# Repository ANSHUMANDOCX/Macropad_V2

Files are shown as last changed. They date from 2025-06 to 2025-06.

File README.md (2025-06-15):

## MACROPAD

This is a 20-key macropad with 2 rotary encoders, 2 analog slide potentiometers, and a 0.91" OLED display.

---

## List of Components

- Pro Micro RP2040  
- SSD1306 0.91" OLED  
- 20 MX-style keys  
- 2 Encoders  
- 2 PTA0643 Slide Potentiometers  
- WS2812B 2020 RGB LEDs  

---

## Plan

I wanted to make a macropad with enough keys for my purpose. I started out by getting a microcontroller with enough pins and one that is able to run CircuitPython, since I wanted to use KMK as the firmware. This can be programmed for MIDI control as well.  
It also has RGB LEDs for underglow.

The OLED screen will be attached via the QWIIC connector onboard.

---

## PCB and Case





## BOM 
### 📦 Component Cost Table

| Item | Supplier | Price (USD) |
|---|---|---|
| Screw & bolt | LCSC | 0.34 |
| Rotary Encoder (DIP-5) | LCSC | 3.01 |
| PTA6043 Potentiometer (10kΩ) | LCSC | 3.37 |
| 1N4148 Diode | LCSC | 0.84 |
|WS2812B 2020 RGB led | LCSC | 1.67 |
|SSD1306 0.91" OLED Display | LCSC | 2.01 |
| SL2.1A | LCSC |1.22 |
| USB A Female | LCSC |0.74 |
| Shipping (LCSC) | LCSC |  3.73 |
| RP2040 Pro Micro + Qwiic | Electronics Comp | 19.43 |
| Keycaps and Keys | Stackskb | 15.88 |
| PCB | JLCPCB | 9.00 |
| Shipping | JLCPCB | 14.00 |
| **Total** | | **$75.24** |

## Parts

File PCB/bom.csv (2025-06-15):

Designator | Footprint | Quantity | Value | LCSC Part #
C1, C2 | 0805 | 2 | 10uF
D1, D10, D11, D12, D13, D14, D15, D16, D17, D18, D19, D2, D20, D3, D4, D5, D6, D7, D8, D9 | D_DO-35_SOD27_P7.62mm_Horizontal | 20 | 1N4148
D21, D22, D23, D24, D25, D26, D27, D28, D29, D30, D31, D32, D33, D34, D35 | LED_WS2812B-2020_PLCC4_2.0x2.0mm | 15 | WS2812B-2020
DM1, DM2, DM3, DM4, DP1, DP2, DP3, DP4, TP11, TP12 | TestPoint_Pad_D1.5mm | 10 | TestPoint
J1 | USB_C_Receptacle_GCT_USB4105-xx-A_16P_TopMnt_Horizontal | 1 | USB_C_Receptacle_USB2.0_16P
R1, R2 | 0603 | 2 | 5.1k
RV1, RV2 | Potentiometer_Bourns_PTA6043_Single_Slide | 2 | R_Potentiometer
SW1, SW10, SW11, SW12, SW13, SW14, SW15, SW16, SW17, SW18, SW19, SW2, SW20, SW3, SW4, SW5, SW6, SW7, SW8, SW9 | CHERRY | 20 | SW_Push
SW21, SW22 | RotaryEncoder_Alps_EC11E-Switch_Vertical_H20mm_CircularMountingHoles | 2 | RotaryEncoder_Switch
TP1 | TestPoint_Pad_D1.0mm | 1 | TestPoint
U1 | MODULE_DEV-18288 | 1 | DEV-18288
U2 | SOIC-16_4.55x10.3mm_P1.27mm | 1 | SL2.1A

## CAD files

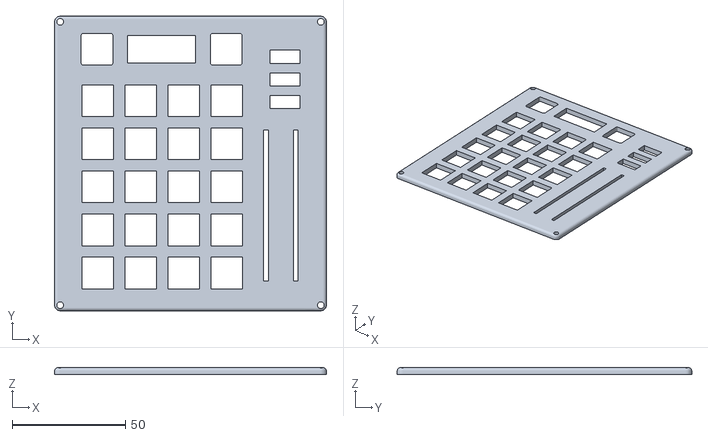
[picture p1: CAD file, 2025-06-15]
CAD/Front Plate v20.stl
120.0 x 130.0 x 3.00

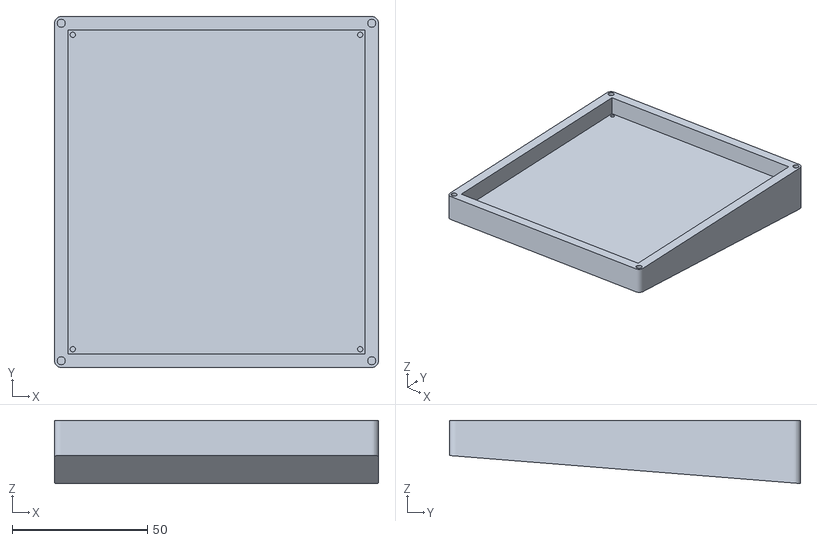
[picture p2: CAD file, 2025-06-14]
CAD/BASE PLATE v6.stl
120.0 x 130.0 x 23.4

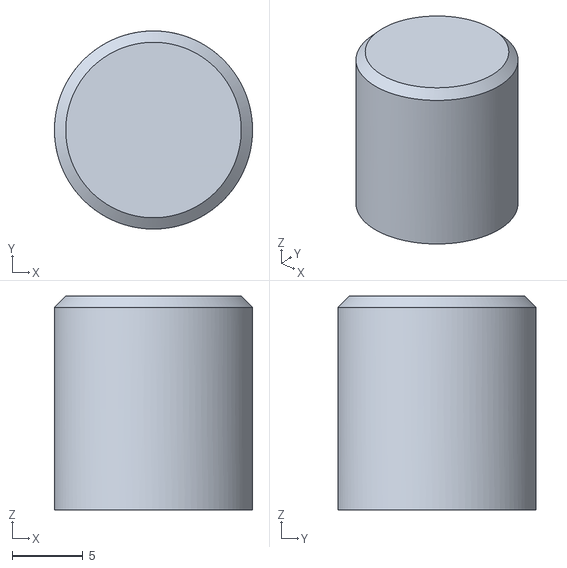
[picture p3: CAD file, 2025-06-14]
CAD/DIAL v1.stl
14.0 x 14.0 x 15.1

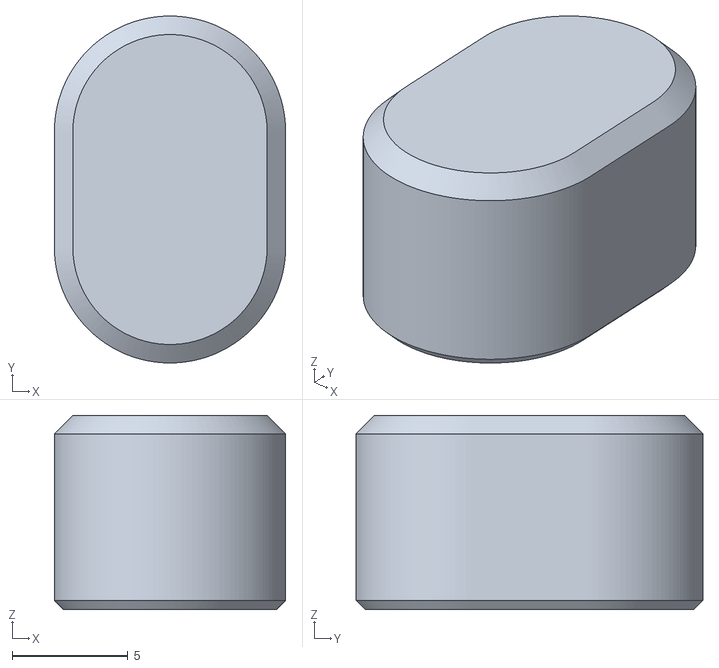
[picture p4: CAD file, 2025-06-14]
CAD/KNOB v1.stl
10.0 x 15.0 x 8.40

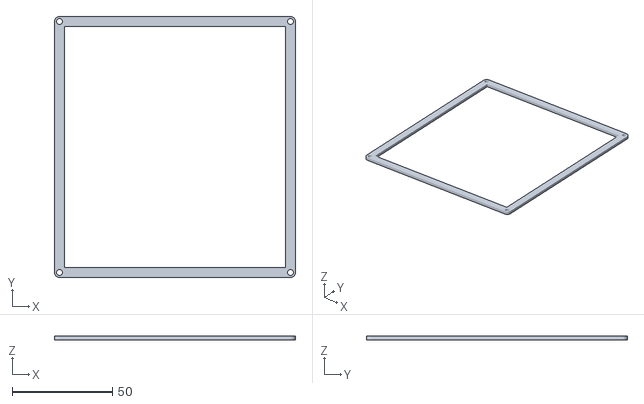
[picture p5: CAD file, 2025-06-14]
CAD/mid layer v1.stl
120.0 x 130.0 x 2.00

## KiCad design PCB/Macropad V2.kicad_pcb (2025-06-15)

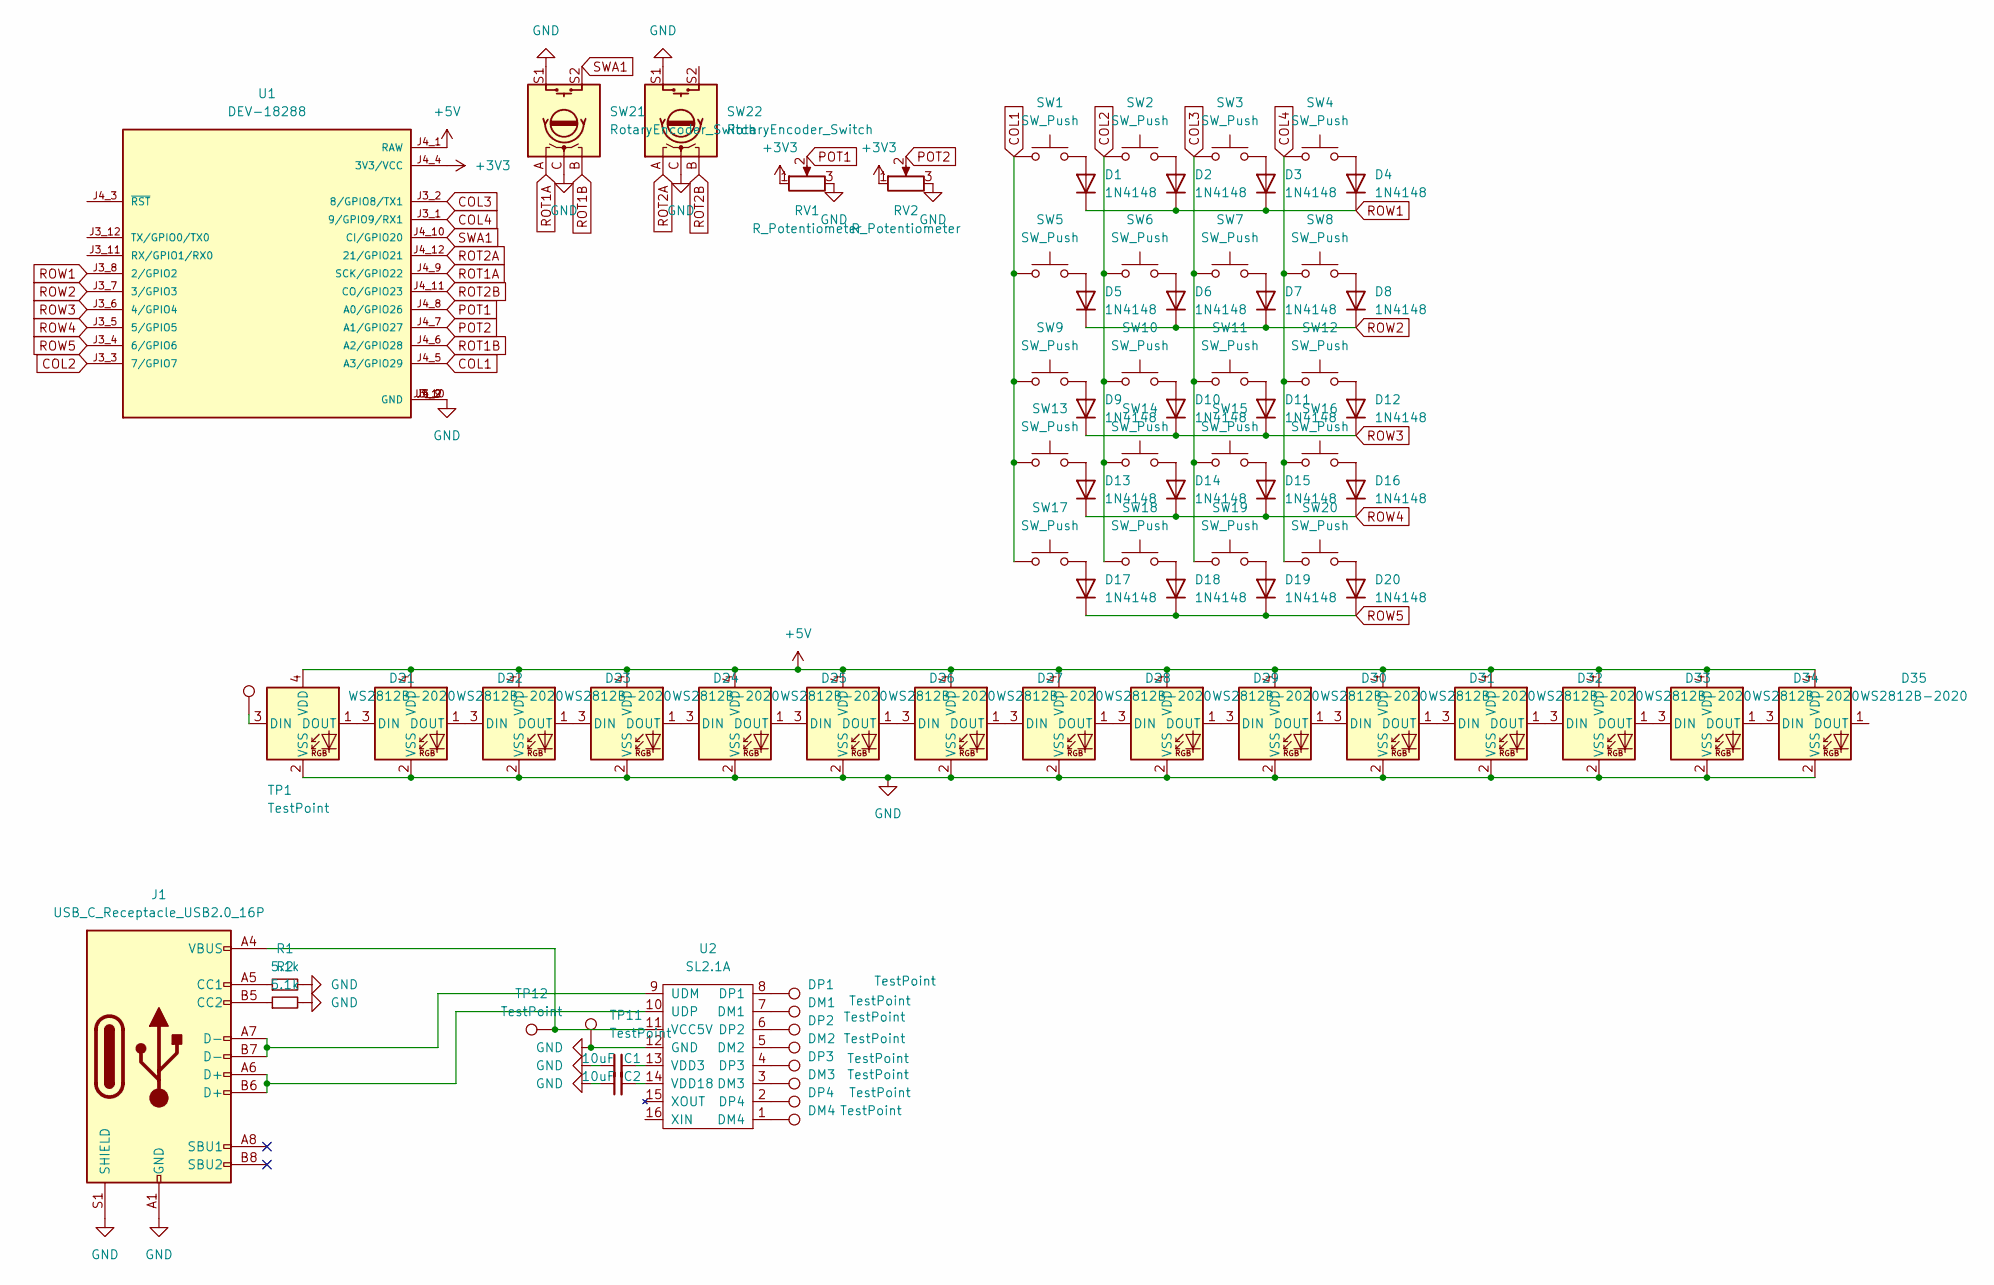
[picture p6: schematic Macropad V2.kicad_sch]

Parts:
C1, C2: 10uF; C_0805_2012Metric
D1, D2, D3, D4, D5, D6, D7, D8, D9, D10, D11, D12, D13, D14, D15, D16, D17, D18, D19, D20: 1N4148; D_DO-35_SOD27_P7.62mm_Horizontal
D21, D22, D23, D24, D25, D26, D27, D28, D29, D30, D31, D32, D33, D34, D35: WS2812B-2020; LED_WS2812B-2020_PLCC4_2.0x2.0mm
DM1, DM2, DM3, DM4: TestPoint; TestPoint_Pad_D1.5mm
DP1, DP2, DP3, DP4: TestPoint; TestPoint_Pad_D1.5mm
J1: USB_C_Receptacle_USB2.0_16P; USB_C_Receptacle_GCT_USB4105-xx-A_16P_TopMnt_Horizontal
R1, R2: 5.1k; R_0603_1608Metric
RV1, RV2: R_Potentiometer; Potentiometer_Bourns_PTA6043_Single_Slide
SW1, SW2, SW3, SW4, SW5, SW6, SW7, SW8, SW9, SW10, SW11, SW12, SW13, SW14, SW15, SW16, SW17, SW18, SW19, SW20: SW_Push; CHERRY
SW21, SW22: RotaryEncoder_Switch; RotaryEncoder_Alps_EC11E-Switch_Vertical_H20mm_CircularMoun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
TP1: TestPoint; TestPoint_Pad_D1.0mm
TP11, TP12: TestPoint; TestPoint_Pad_D1.5mm
U1: DEV-18288; MODULE_DEV-18288; PARTREV v11
U2: SL2.1A; SOIC-16_4.55x10.3mm_P1.27mm

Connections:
+3V3: RV1.1, RV2.1, U1.J4_4 (3V3/VCC)
+5V: D21.4 (VDD), D22.4 (VDD), D23.4 (VDD), D24.4 (VDD), D25.4 (VDD), D26.4 (VDD), D27.4 (VDD), D28.4 (VDD), D29.4 (VDD), D30.4 (VDD), D31.4 (VDD), D32.4 (VDD), D33.4 (VDD), D34.4 (VDD), D35.4 (VDD), U1.J4_1 (RAW)
COL1: SW1.1, SW5.1, SW9.1, SW13.1, SW17.1, U1.J4_5 (A3/GPIO29)
COL2: SW2.1, SW6.1, SW10.1, SW14.1, SW18.1, U1.J3_3 (7/GPIO7)
COL3: SW3.1, SW7.1, SW11.1, SW15.1, SW19.1, U1.J3_2 (8/GPIO8/TX1)
COL4: SW4.1, SW8.1, SW12.1, SW16.1, SW20.1, U1.J3_1 (9/GPIO9/RX1)
GND: C1.1, C2.1, D21.2 (VSS), D22.2 (VSS), D23.2 (VSS), D24.2 (VSS), D25.2 (VSS), D26.2 (VSS), D27.2 (VSS), D28.2 (VSS), D29.2 (VSS), D30.2 (VSS), D31.2 (VSS), D32.2 (VSS), D33.2 (VSS), D34.2 (VSS), D35.2 (VSS), J1.A1 (GND), J1.A12 (GND), J1.B1 (GND), J1.B12 (GND), J1.S1 (SHIELD), R1.2, R2.2, RV1.3, RV2.3, SW21.C, SW21.S1, SW22.C, SW22.S1, TP11.1, U1.J3_9 (GND), U1.J3_10 (GND), U1.J4_2 (GND), U2.12 (GND)
unnamed: D1.2 (A), SW1.2
unnamed: D2.2 (A), SW2.2
unnamed: D3.2 (A), SW3.2
unnamed: D4.2 (A), SW4.2
unnamed: D5.2 (A), SW5.2
unnamed: D6.2 (A), SW6.2
unnamed: D7.2 (A), SW7.2
unnamed: D8.2 (A), SW8.2
unnamed: D9.2 (A), SW9.2
unnamed: D10.2 (A), SW10.2
unnamed: D11.2 (A), SW11.2
unnamed: D12.2 (A), SW12.2
unnamed: D13.2 (A), SW13.2
unnamed: D14.2 (A), SW14.2
unnamed: D15.2 (A), SW15.2
unnamed: D16.2 (A), SW16.2
unnamed: D17.2 (A), SW17.2
unnamed: D18.2 (A), SW18.2
unnamed: D19.2 (A), SW19.2
unnamed: D20.2 (A), SW20.2
unnamed: D21.3 (DIN), TP1.1
unnamed: D21.1 (DOUT), D22.3 (DIN)
unnamed: D22.1 (DOUT), D23.3 (DIN)
unnamed: D23.1 (DOUT), D24.3 (DIN)
unnamed: D24.1 (DOUT), D25.3 (DIN)
unnamed: D25.1 (DOUT), D26.3 (DIN)
unnamed: D26.1 (DOUT), D27.3 (DIN)
unnamed: D27.1 (DOUT), D28.3 (DIN)
unnamed: D28.1 (DOUT), D29.3 (DIN)
unnamed: D29.1 (DOUT), D30.3 (DIN)
unnamed: D30.1 (DOUT), D31.3 (DIN)
unnamed: D31.1 (DOUT), D32.3 (DIN)
unnamed: D32.1 (DOUT), D33.3 (DIN)
unnamed: D33.1 (DOUT), D34.3 (DIN)
unnamed: D34.1 (DOUT), D35.3 (DIN)
unnamed: J1.A5 (CC1), R1.1
unnamed: J1.B5 (CC2), R2.1
unnamed: DM1.1, U2.7 (DM1)
unnamed: DM2.1, U2.5 (DM2)
unnamed: DM3.1, U2.3 (DM3)
unnamed: DM4.1, U2.1 (DM4)
unnamed: DP1.1, U2.8 (DP1)
unnamed: DP2.1, U2.6 (DP2)
unnamed: DP3.1, U2.4 (DP3)
unnamed: DP4.1, U2.2 (DP4)
unnamed: J1.A7 (D-), J1.B7 (D-), U2.9 (UDM)
unnamed: J1.A6 (D+), J1.B6 (D+), U2.10 (UDP)
unnamed: J1.A4 (VBUS), J1.A9 (VBUS), J1.B4 (VBUS), J1.B9 (VBUS), TP12.1, U2.11 (VCC5V)
unnamed: C1.2, U2.13 (VDD3)
unnamed: C2.2, U2.14 (VDD18)
POT1: RV1.2, U1.J4_8 (A0/GPIO26)
POT2: RV2.2, U1.J4_7 (A1/GPIO27)
ROT1A: SW21.A, U1.J4_9 (SCK/GPIO22)
ROT1B: SW21.B, U1.J4_6 (A2/GPIO28)
ROT2A: SW22.A, U1.J4_12 (21/GPIO21)
ROT2B: SW22.B, U1.J4_11 (CO/GPIO23)
ROW1: D1.1 (K), D2.1 (K), D3.1 (K), D4.1 (K), U1.J3_8 (2/GPIO2)
ROW2: D5.1 (K), D6.1 (K), D7.1 (K), D8.1 (K), U1.J3_7 (3/GPIO3)
ROW3: D9.1 (K), D10.1 (K), D11.1 (K), D12.1 (K), U1.J3_6 (4/GPIO4)
ROW4: D13.1 (K), D14.1 (K), D15.1 (K), D16.1 (K), U1.J3_5 (5/GPIO5)
ROW5: D17.1 (K), D18.1 (K), D19.1 (K), D20.1 (K), U1.J3_4 (6/GPIO6)
SWA1: SW21.S2, U1.J4_10 (CI/GPIO20)

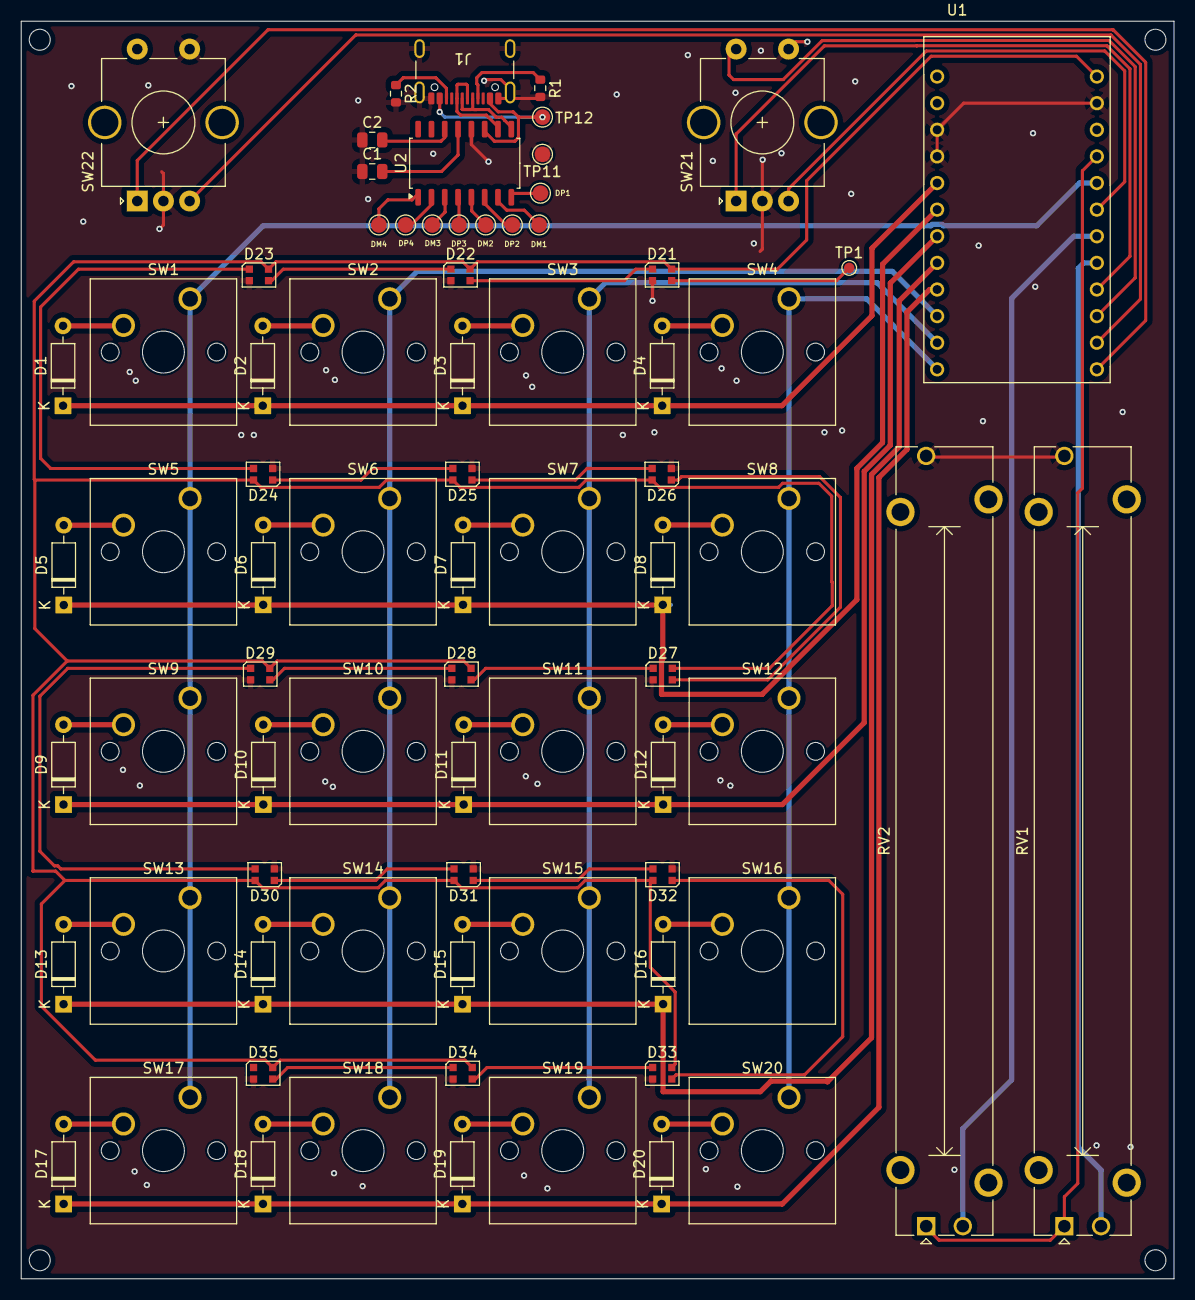
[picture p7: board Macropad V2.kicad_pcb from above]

Board: 2 copper layers, 110.0 x 120.0 mm, 77 parts (0 on the bottom side), 69 nets.

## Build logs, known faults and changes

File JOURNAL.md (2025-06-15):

# Macropad_V2
- **Title:** Macropad V2
- **Author:** Anshuman Tripathy
- **Description:** Macropad with 20 keys 2 encoders and 2 sliding potentiometers as analog input along with a Oled Display 
- **Created_at:** 2025-06-02
- Total Time Spent: 14 hr
----

# **DAY 1- 2 June: Choosing the MCU**

Started out by planning the number of I/O pins I would require. Since I will be using KMK, I need to find a board with enough GPIOs and also supports CircuitPython. After searching for a bit, I decided on using the SparkFun Pro Micro RP2040.

**Time Spent= 1.5hr**

---

# **DAY 2 - 3 June : Completed the schematic**

Started out with the Schematic i will be connecting the OLED display to the QWIIC connector on the promicro rp2040.
will be using WS2812B 2020 led for a RGB under glow. I will be making a 5x4 matrix of the keys.
There is pad under the RP2040 that connects to the onboard rgb led i will be utilsing the same pin to connect my leds.



**Time Spent = 1.5hr**

---
# **DAY 3 - 4th June : Started out with the PCB layout**

Started and complted the PCB layout and Routing. Used the Keyboard layout website to generate the layout and used the Kicad plugin to arrange the keys. 



**Time Spent- 2hr**

---

# **DAY 4 - 6 June: Started out with the 3d model**

Complted the PCB and added the mounting holes for the PCB and started and completed the Base plate of the case



**Time Spent- 2hr**
---
# **DAY 5 - 7 June: Completed the CAD**

Started out with the front plate for the case and complted it. Also imported the PCB step file and checked all the fitting and complted the cad Modelling. Generated the cutouts for the keys from a website. Had to make many iterations for the front plate to make it a proper fit.




**Time Spent- 3hr**

# **DAY 6 - 15 June: Made Slight asthetical changes**

added a ~5 degree tilt to the macropad, Designed Knobs( had planned to use premade one but decided not to) also added a translucent mid layer for having a better rgb look. 
Also added the feaure of a usb hub a the empty place that was above the MCU. it has 3 ports. 





**Time spent 4hr**

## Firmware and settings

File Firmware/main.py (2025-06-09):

print("Starting")

import board
from kmk.kmk_keyboard import KMKKeyboard
from kmk.keys import KC
from kmk.scanners import DiodeOrientation
from kmk.modules.encoder import EncoderHandler
from kmk.extensions.media_keys import MediaKeys
from kmk.modules.layers import Layers


keyboard = KMKKeyboard()

keyboard.col_pins = (board.D10, board.D9, board.D8)
keyboard.row_pins = (board.D5, board.D4, board.D3)
keyboard.diode_orientation = DiodeOrientation.COL2ROW

encoder_handler = EncoderHandler()
layer = Layers()

keyboard.modules.append(encoder_handler)
keyboard.modules.append(MediaKeys())
keyboard.modules.append(layer)

TRANS = KC.TRANS
RAISE = KC.LT(1,KC.ESC)
RAISE1 = KC.LT(2,KC.F)
#RAISE = KC.DF(1)
#DOWN = KC.DF(0)

encoder_handler.pins = ((board.D2, board.D1, board.D0),)
encoder_handler.map = [
    ((KC.VOLU, KC.VOLD, KC.MUTE),)
]

keyboard.keymap = [
    [#Layer 0
        RAISE, KC.BACKSPACE, KC.PSCR,
        RAISE1, KC.ENTER, KC.LGUI(KC.TAB),
        KC.LEFT, KC.SPACE, KC.RIGHT
    ],
    [#Layer 1
        TRANS,KC.LCTRL(KC.Y),KC.LALT(KC.F4),
        KC.LCTRL(KC.C),KC.LCTRL(KC.V),KC.LCTRL(KC.Z),
        KC.MPRV,KC.MPLY,KC.MNXT,
    ],
    [
        KC.X,KC.LALT,KC.TAB,
        TRANS,KC.W,KC.UP,
        KC.A,KC.X,KC.DOWN
    ]
]

if __name__ == '__main__':
    keyboard.go()
